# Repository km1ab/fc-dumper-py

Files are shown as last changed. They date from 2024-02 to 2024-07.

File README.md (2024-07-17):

# FC dumper py

- Dumper for fc by Python.
- This dumper is a HAT for Raspberry Pi and we also publish the source code to make it work in this repository.

## Environment
- Raspberry pi 3 b+, or later
- Raspberry pi zero, or later

```
Unsupported on Raspberry pi 5. "RPi.GPIO" is no longer available from Raspberry pi 5. 
We are currently looking into alternatives.
```

## How to use
At Raspberry pi, or remote connecting (ex ssh,...)
```
pip install RPi.GPIO
python3 fc_dumper.py -o filename
```

```
$ python3 fc_dumpter.py --help
usage: fc_dumpter.py [-h] [-o OUTPUT_FILE] [-p {8K,16K,32K}] [-c {1K,8K,16K,32K}] [-a {mapper0,mapper1,mapper3,mapper66,mapper23}] [-m {dumper,led_test}] [-d [DEBUG]] [-i [INFO]] [-s SIZE]
                     [-D [LED_DUTY ...]] [-F [LED_FREQ ...]] [-N [LED_NUMBER ...]] [-T LED_TIME]

options:
  -h, --help            show this help message and exit
  -o OUTPUT_FILE, --output_file OUTPUT_FILE
                        output file name; (default: output.nes)
  -p {8K,16K,32K}, --prg_rom_size {8K,16K,32K}
                        program rom size select; (default: 16K)
  -c {1K,8K,16K,32K}, --chr_rom_size {1K,8K,16K,32K}
                        charactor rom size select; (default: 8K)
  -a {mapper0,mapper1,mapper3,mapper66,mapper23}, --mapper {mapper0,mapper1,mapper3,mapper66,mapper23}
                        mapper select; In mapper 23, specify the size of the bank in options '-p' and '-c'. (default: mapper0)
  -m {dumper,led_test}, --mode {dumper,led_test}
                        mode (default: dumper)
  -d [DEBUG], --debug [DEBUG]
                        debug log (default: False)
  -i [INFO], --info [INFO]
                        game infomation (default: False)
  -s SIZE, --size SIZE  read size (default: 256)
  -D [LED_DUTY ...], --led_duty [LED_DUTY ...]
                        LED testing only (default: [1])
  -F [LED_FREQ ...], --led_freq [LED_FREQ ...]
                        LED testing only (default: [20])
  -N [LED_NUMBER ...], --led_number [LED_NUMBER ...]
                        LED testing only (default: [0])
  -T LED_TIME, --led_time LED_TIME
                        LED testing only (default: 5)
```

## Hardware
- PCB-top
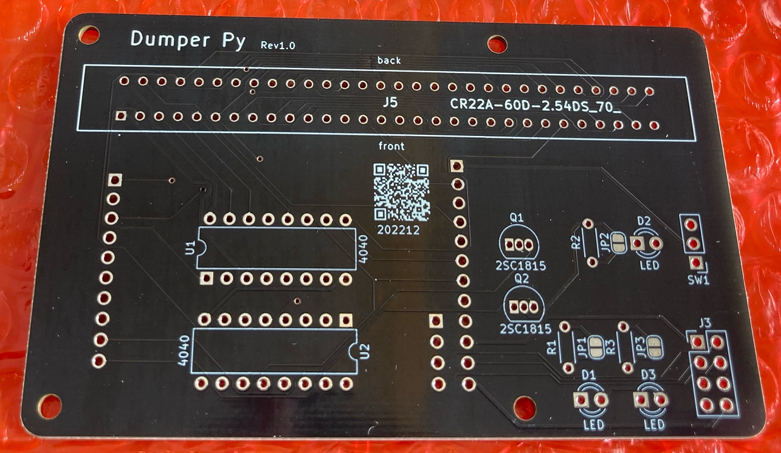
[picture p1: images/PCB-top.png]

- PCB-bottom
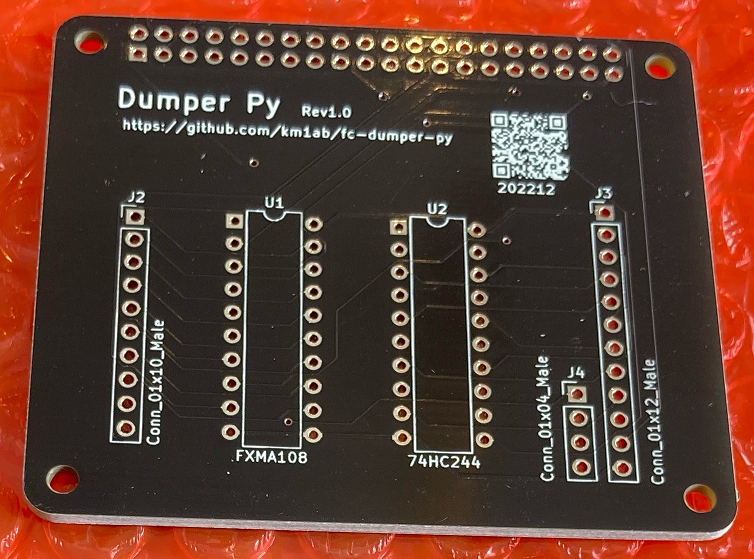
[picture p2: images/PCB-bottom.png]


## Parts list
必須

| 名称 | 数量 | 入手先 | 備考 |
|---|----|---|---|
| PCB-top (rev1.0) | 1  | 頒布予定 | 本ページのHardwareを参照 |
| PCB-bottom (rev1.0) | 1  | 頒布予定 | 本ページのHardwareを参照 |
| ラズパイ 3 b+ | 1  | メルカリ？など  | ラズパイ5が発売されました。少々高いですが、容量の少ない方が比較的入手しやすいようです。2024/03現在。 |
| CR22A-60D-2.54DS(70) | 1  | ⇒⇒⇒ | googleにて、CR22A-60D-2.54DS(70)で検索すると、ある程度ヒットします。 |
| 抵抗内蔵５ｍｍＬＥＤ（※） | 1  | 秋月電子 | https://akizukidenshi.com/catalog/g/gI-12517/ |
| 小型スライドスイッチ　１回路２接点 | 1  | 秋月電子 | https://akizukidenshi.com/catalog/g/gP-12723/ |
| 8ビット双方向ロジックレベル変換モジュール（FXMA108） | 1  | 秋月電子 | https://akizukidenshi.com/catalog/g/g104522/ |
| 74HC244 | 1  | マルツオンライン | https://www.marutsu.co.jp/GoodsDetail.jsp?salesGoodsCode=37576&shopNo=3 |
| 74HC4040 | 2  | マルツオンライン | https://www.marutsu.co.jp/pc/i/18963/ |
| Raspberry Pi専用スペーサー（MPS-M2611） | 1  | サンハヤト | https://shop.sunhayato.co.jp/products/mps-m2611 |
| 六角オネジ・メネジ　ＭＢ２６－１１ | 4  | 秋月電子 | https://akizukidenshi.com/catalog/g/gP-11546/ |
| ピンソケット (メス) 2×20 (40P) | 1  | 秋月電子 | https://akizukidenshi.com/catalog/g/g100085/ |
| ピンソケット(メス) 1×12(12P) | 1  | 秋月電子 | https://akizukidenshi.com/catalog/g/g110101/ |
| ピンソケット(メス) 1×10(10P) | 1  | 秋月電子 | https://akizukidenshi.com/catalog/g/g103786/ |
| ピンヘッダ 1×4 (4P)　10個入り（※） | 1  | 秋月電子 | https://akizukidenshi.com/catalog/g/g103950/ |
| ピンヘッダ 1×40 (40P) | 1  | 秋月電子 | https://akizukidenshi.com/catalog/g/g100167/ |
| ICソケット (16P)　10個入り（※） | 1  | 秋月電子 | https://akizukidenshi.com/catalog/g/g100007/ |
| ICソケット (20P)　10個入り（※） | 1  | 秋月電子 | https://akizukidenshi.com/catalog/g/g100009/ |

※LEDは、いかにも電源ONでスライドスイッチ真横のLED(D2)が光りそうですが、実際D3の方が光ります。<br>
　また、必ずしも内臓抵抗のものである必要がありません。<br>
　5mm LEDと抵抗の組み合わせでも良いです。<br>
　回路図をご覧頂くとわかるかと思います。<br>
※ピンヘッダ 1×4 (4P)は、1個しか使いません。バラで購入できるならそれで問題ありません。<br>
※ICソケットはそれぞれ2個使います。バラで購入できるならそれで問題ありません。<br>
　ただ、ICソケットは有りでも無しでも好きな方で。<br>

#### オプション
- 抵抗内蔵５ｍｍＬＥＤ x2
- トランジスタ　２ＳＣ１８１５ x2
- ※抵抗内蔵LEDを使わない場合は、抵抗x3（抵抗値はLEDのスペックによる）
- Bottom ケース：3Dプリンタで作りました。3B+用に適当に作っています　(データ：stl/raspi_case_4_2.stl)
- ピンヘッダ 2×20 (40P) ※2x4(8P)分しか使いません。デバッグ用なので無くても問題ありせん。
### 完成図
- ラズパイと接続するとこのような見た目になります。
- ２段のスタック構造になっています。
- ※Raspberry Pi専用スペーサーのナットは使いませんでした。

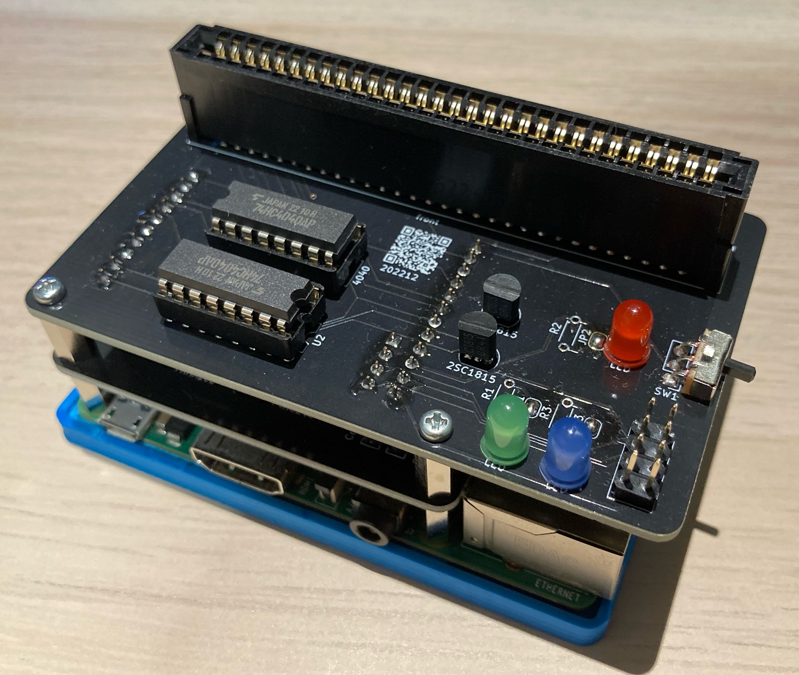
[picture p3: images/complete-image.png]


### 分割した様子
#### face and bottom
- face
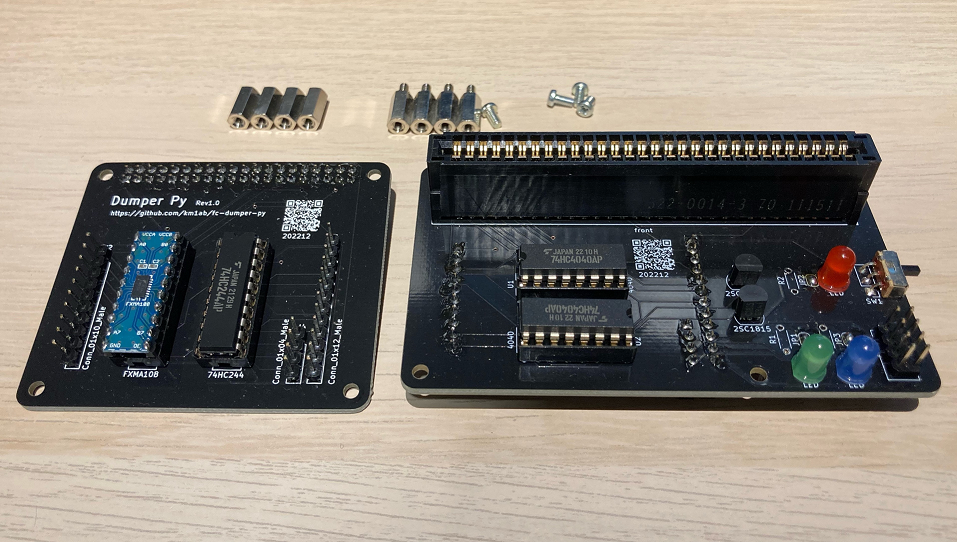
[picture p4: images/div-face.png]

- bottom
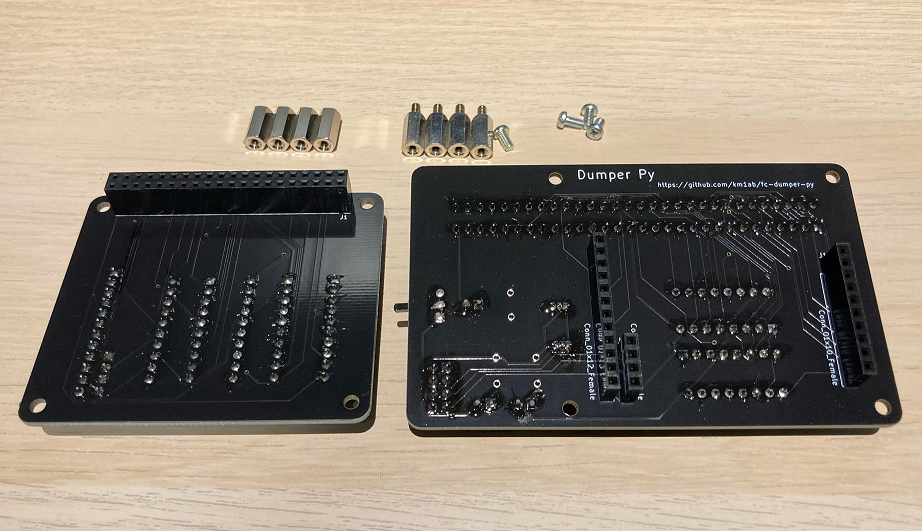
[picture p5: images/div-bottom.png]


### 留意事項
#### FXMA108の取り付けについて
- FXMA108のキットは、付属のピンヘッダをそのまま取り付けると、隣のHC244より背が高くなります。<br>それに伴い、PCB-TOPをスタックする時に干渉してしまいますので、以下に取付方法を記載致します。
- 方法１
  - ピンヘッダの足を適当な長さに切りそろえて下さい。
  - また、付属のピンヘッダの足は太いので、ICソケットに若干強引に差し込みます（問題なくささりますが）。
  - なので、気になる方は細ピンヘッダを使うと良いかもしれません。
- もう１つの方法
  - ICソケットも、ピンヘッダも使わずに直に取り付けてしまう方法です。
  - FXMA108のキットに以下のような説明がありました。簡単な方をお試しください。
```
スルーホール部分をルータ加工することで、ユニバーサル基板等に直接ハンダ付け可能となっています。（※）
```
※8ビット双方向ロジックレベル変換モジュールのマニュアルより引用。

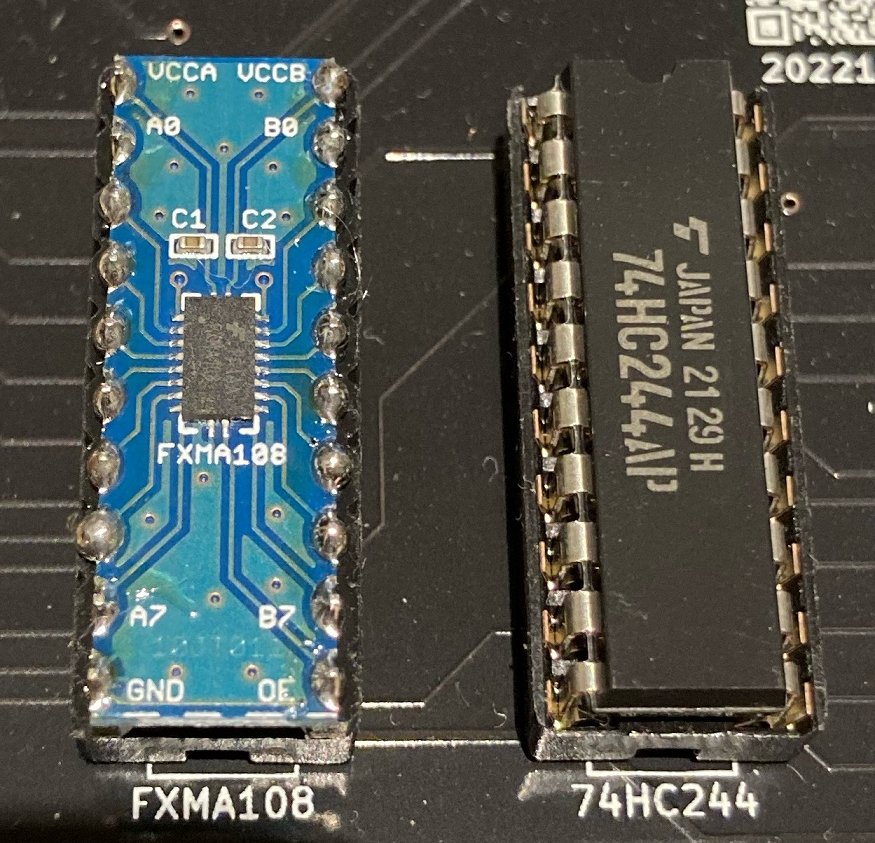
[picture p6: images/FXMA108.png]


### PCB design

#### top PCB
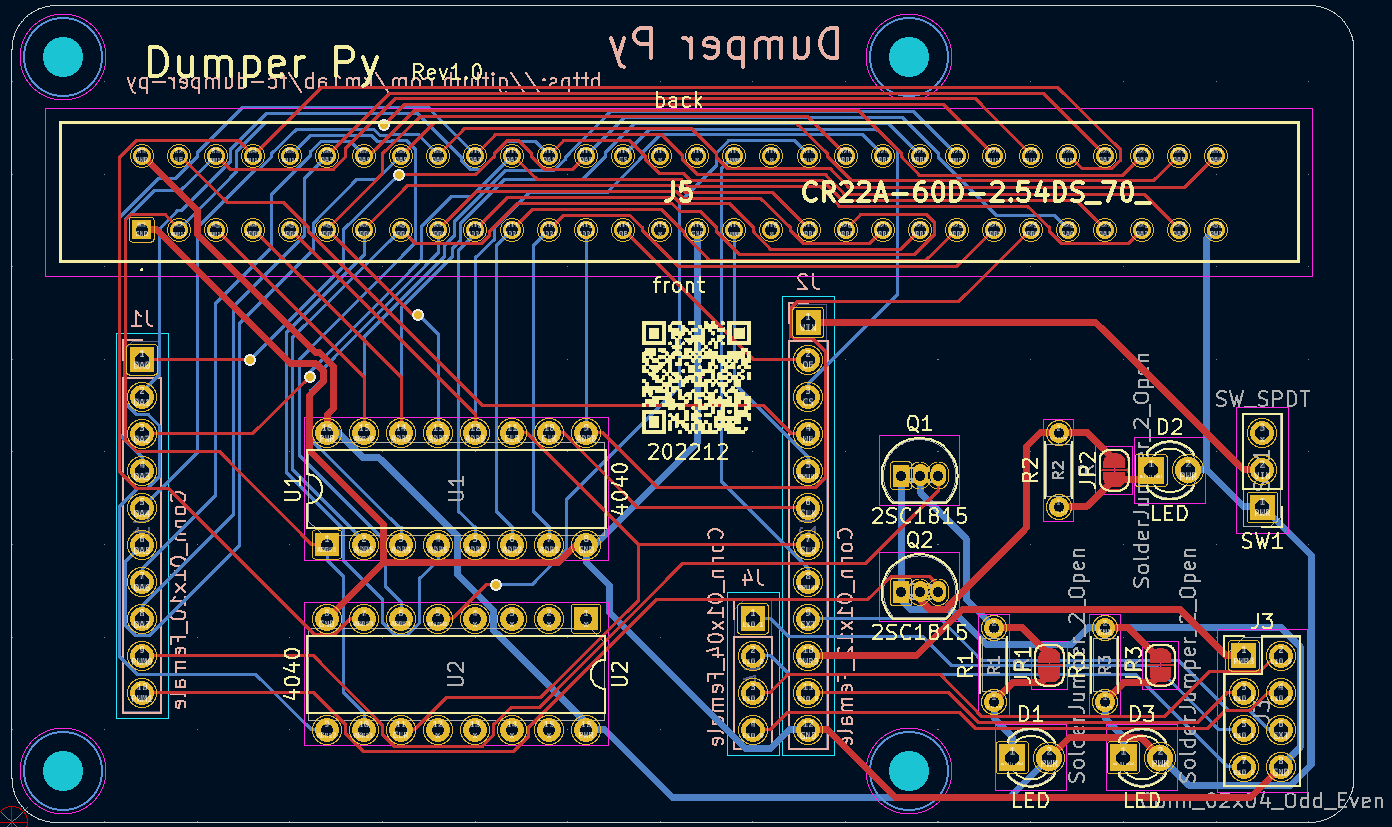
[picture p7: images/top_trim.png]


#### bottom PCB
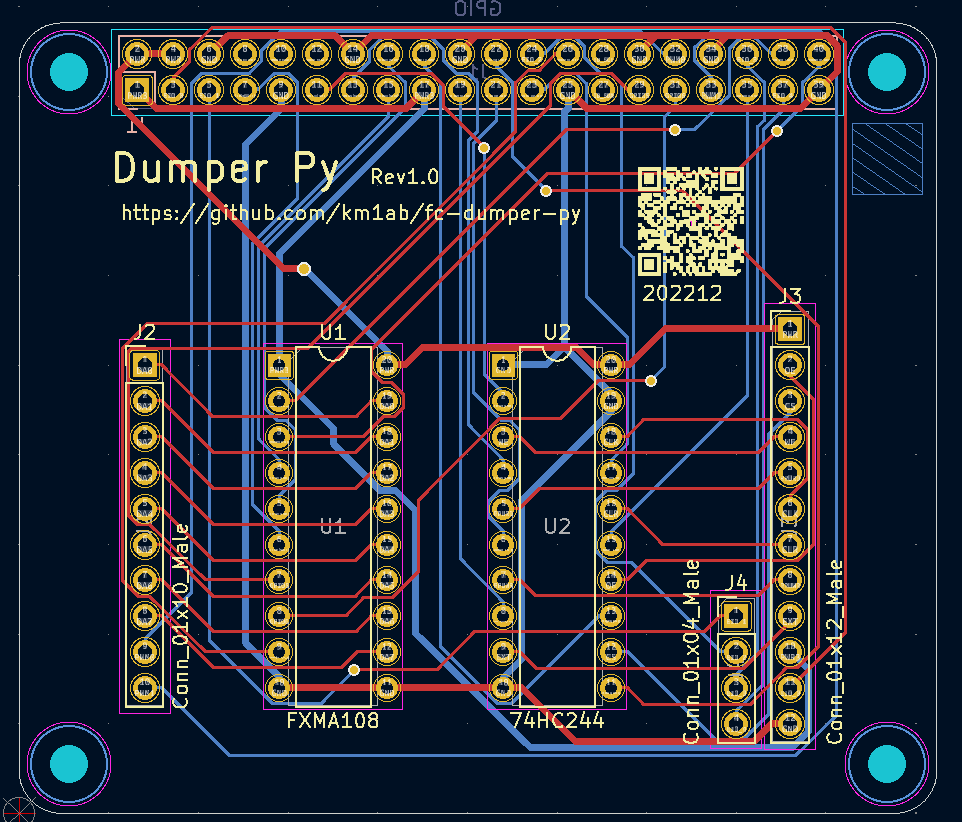
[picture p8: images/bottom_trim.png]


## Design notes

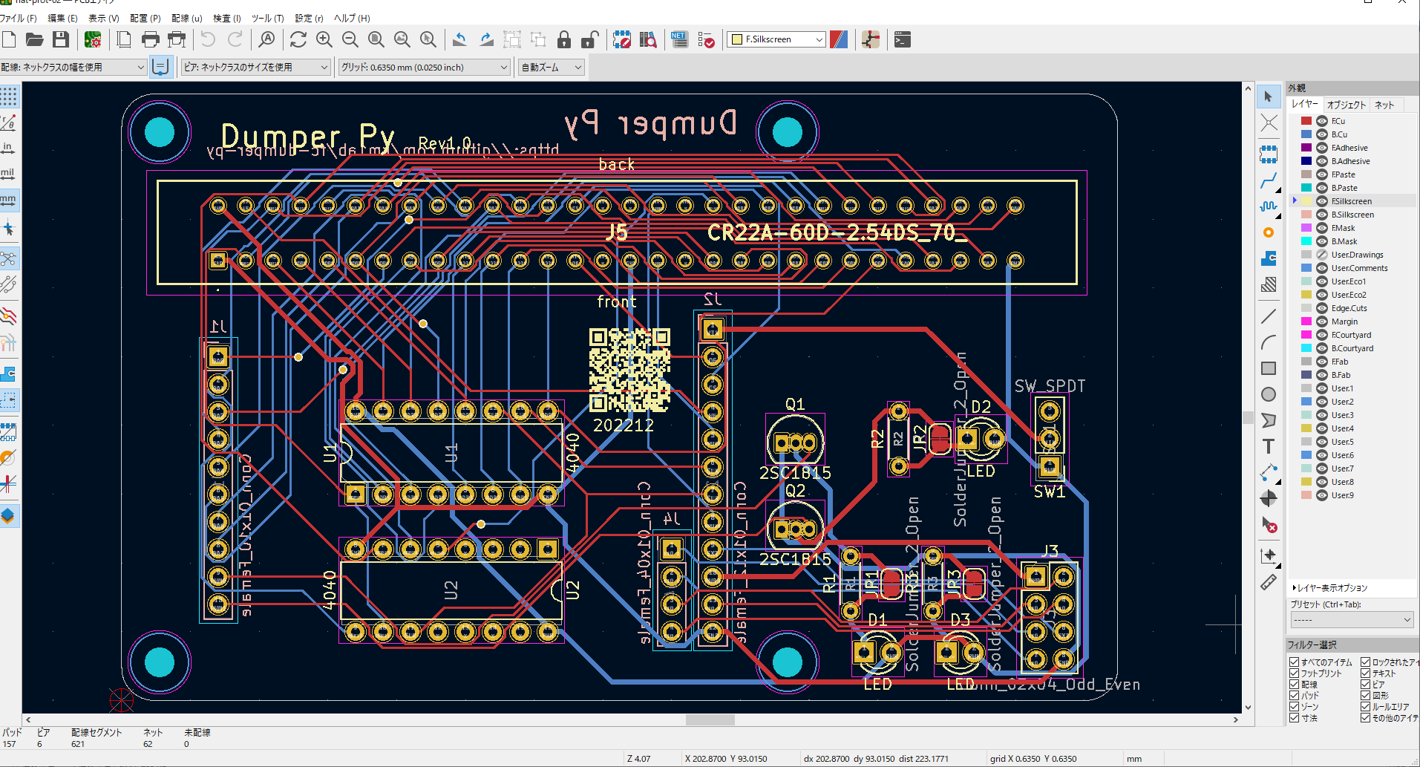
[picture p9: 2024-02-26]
images/top.PNG

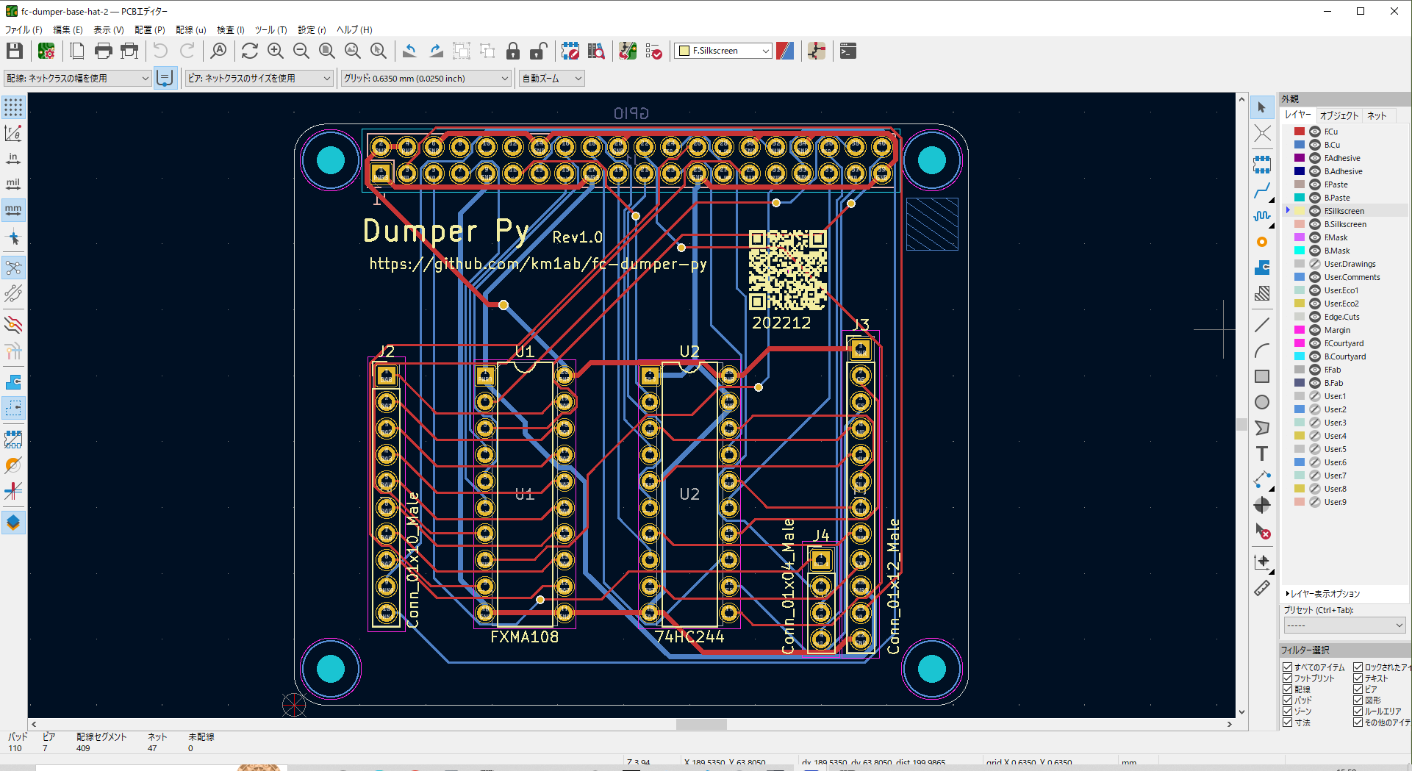
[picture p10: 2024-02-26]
images/bottom.PNG

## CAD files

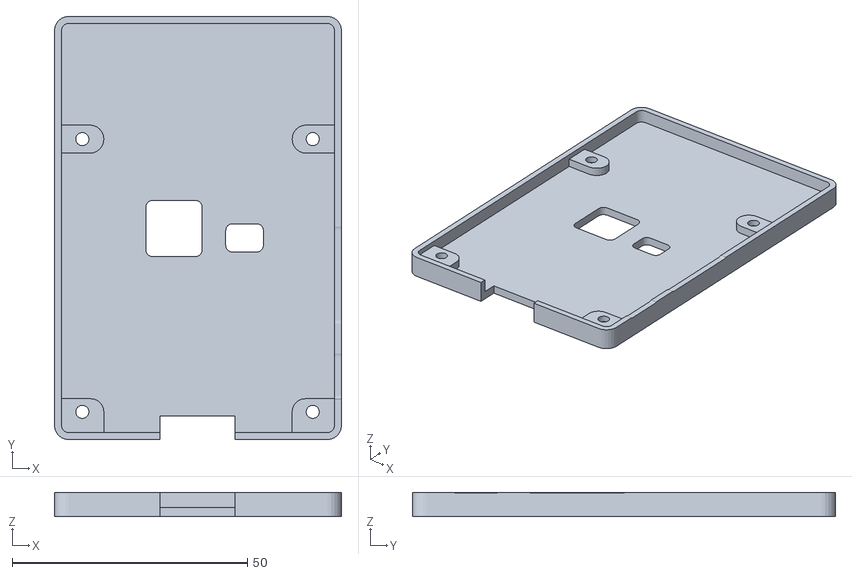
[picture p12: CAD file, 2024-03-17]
stl/raspi_case_4_2.stl
61.0 x 90.0 x 5.20

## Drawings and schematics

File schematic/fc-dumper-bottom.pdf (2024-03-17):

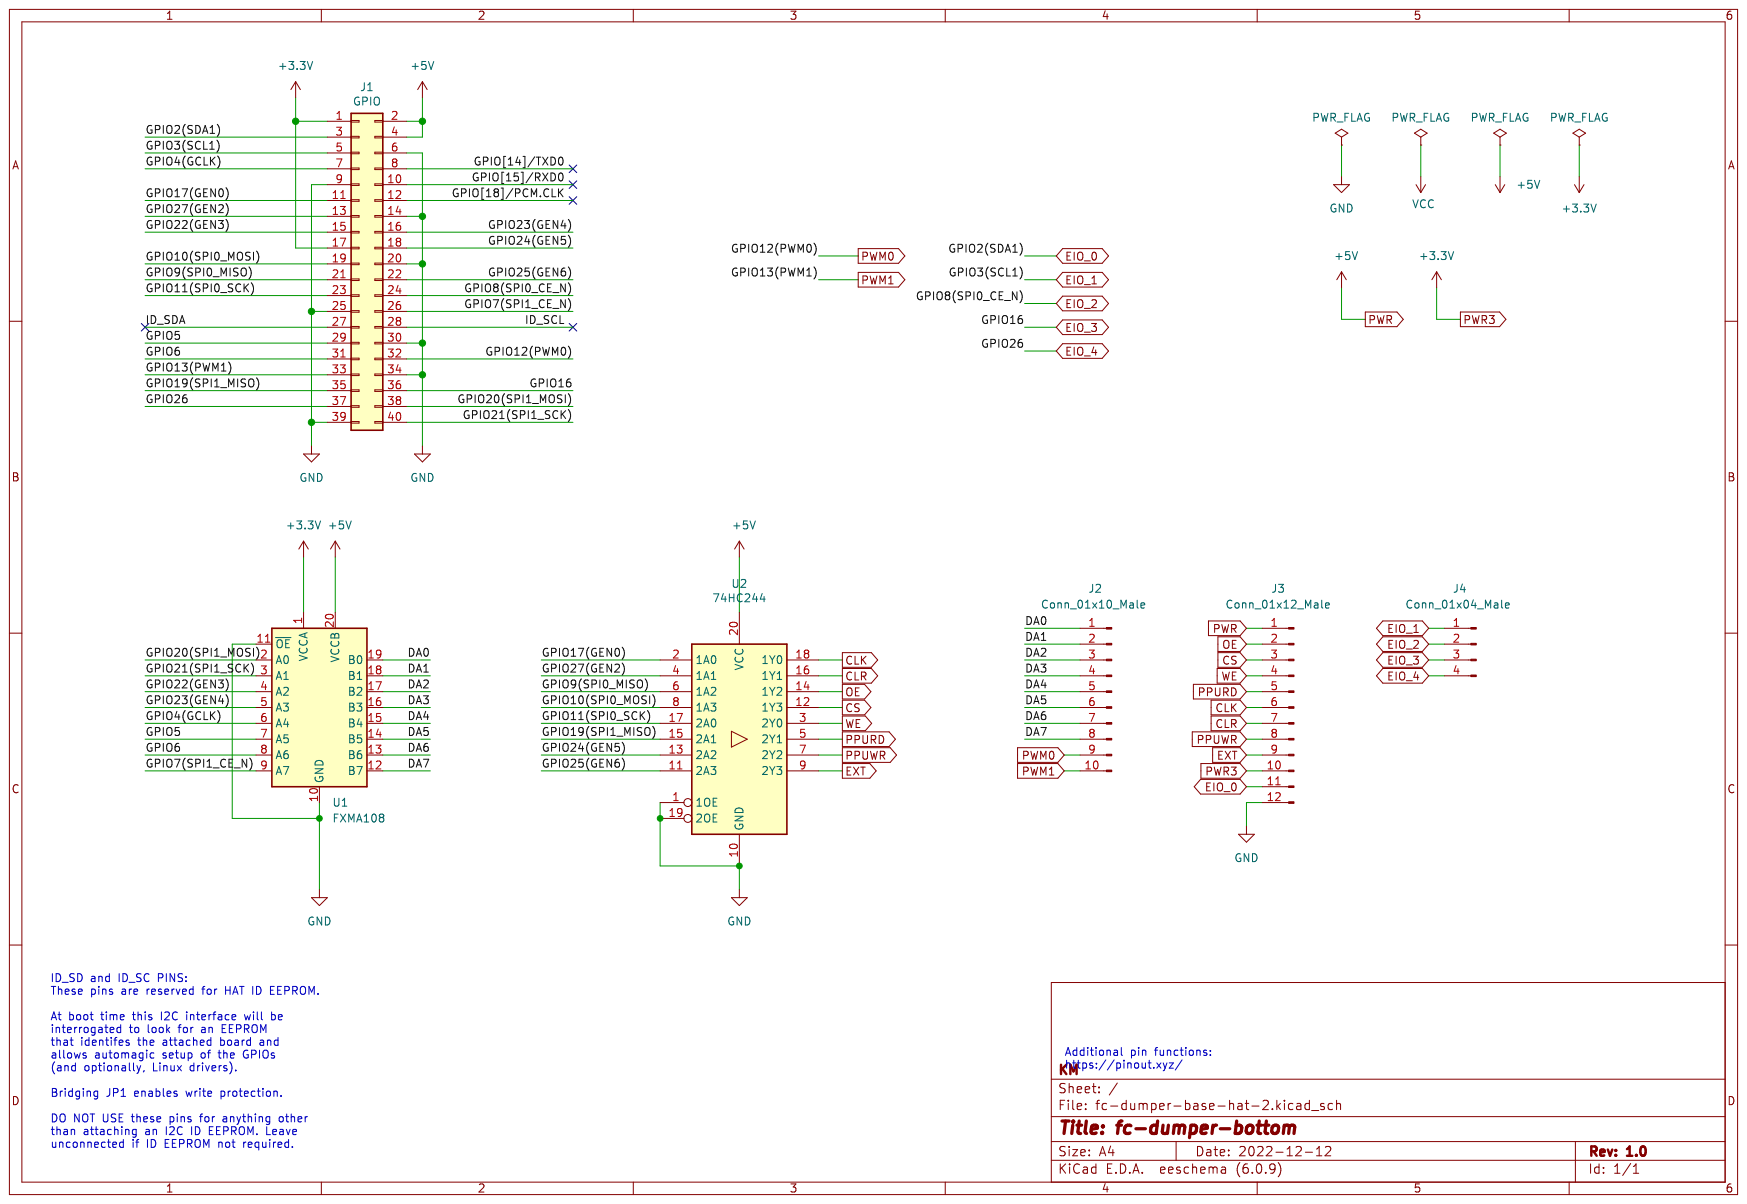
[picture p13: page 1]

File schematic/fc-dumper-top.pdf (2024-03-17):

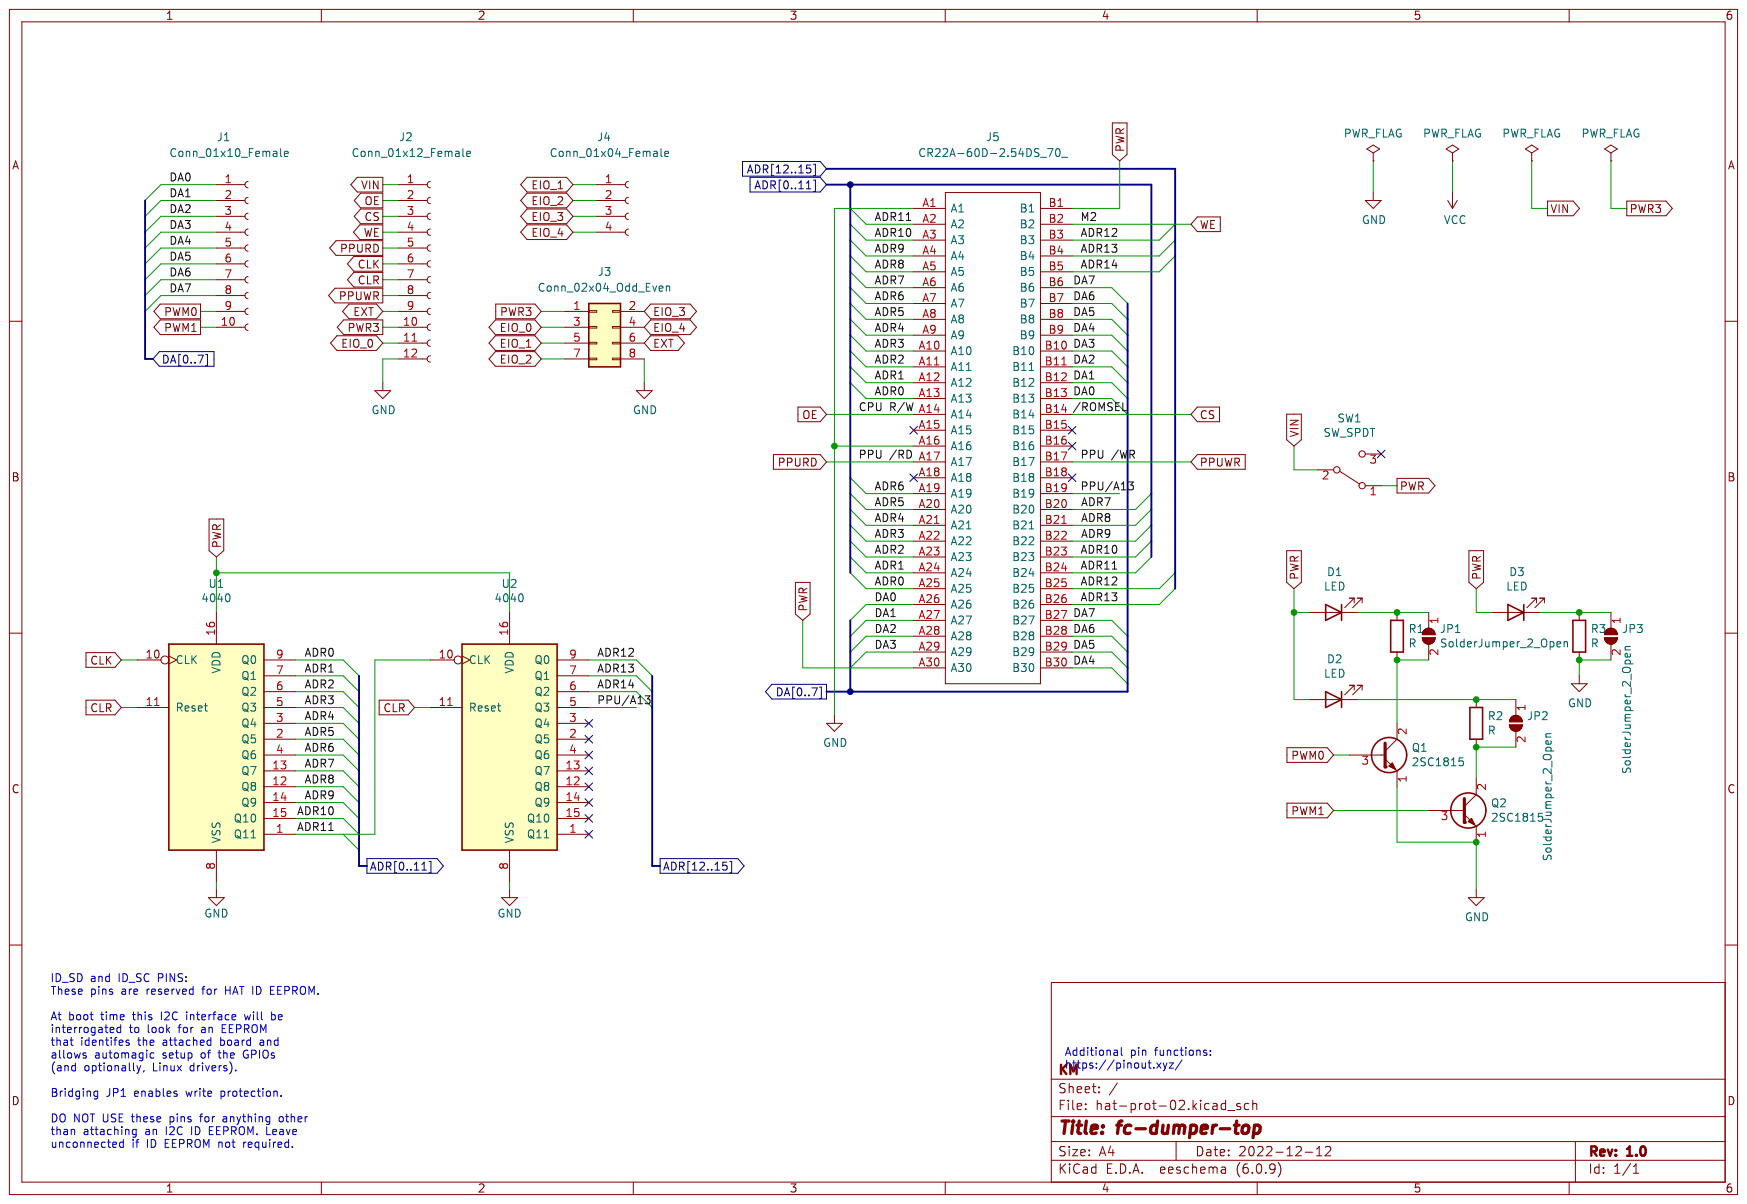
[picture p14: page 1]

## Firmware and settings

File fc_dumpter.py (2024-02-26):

import sys
import RPi.GPIO as GPIO
import time
from argparse import ArgumentParser, ArgumentDefaultsHelpFormatter

INTV = 0.005
# CLK	#RESET
port_tbl_addr_ctrl = [17, 27]

port_tbl_data_ctrl = [20, 21, 22, 23, 4, 5, 6, 7]
# CPU R/W	# /ROMSEL	# M2	# PPU /RD   # PPU /WR  # EXT PIN
port_tbl_port_ctrl = [9, 10, 11, 19, 24, 25]

# PWM0 # PWM1
port_tbl_pwm_ctrl = [12, 13]

HEADER_DATA_COMMON = [0x4E, 0x45, 0x53, 0x1A]

HEADER_DATA_COMMON_FOOTER = [0x00, 0x00, 0x00, 0x00, 0x00, 0x00, 0x00, 0x00]
HEADER_DATA_MAPPER0 = [
    # mapper 0
    0x01,
    0x01,
    0x00,
    0x00,
]

HEADER_DATA_MAPPER3 = [
    # mapper 3
    0x02,
    0x04,
    0x31,
    0x00,
]

HEADER_DATA_MAPPER66 = [
    # mapper 66
    0x08,
    0x04,
    0x21,
    0x40,
]

HEADER_DATA_MAPPER1 = [
    # mapper 1
    0x10,
    0x00,
    0x10,
    0x00,
]

HEADER_DATA_MAPPER23 = [
    # mapper 23
    0x08,
    0x10,
    0x71,
    0x10,
]

SIZE_1K = "1K"
SIZE_8K = "8K"
SIZE_16K = "16K"
SIZE_32K = "32K"
# SIZE_64K = "64K"
# SIZE_128K = "128K"
# rom_size: int = 0x4000  # PRG-ROM 16K
# chr_size: int = 0x2000  # CHR-ROM 8K
ROM_SIZE_DICT = {SIZE_1K: 0x400, SIZE_8K: 0x2000, SIZE_16K: 0x4000, SIZE_32K: 0x8000}

BANK_KEY_LIST = [0x30, 0x31, 0x32, 0x33]  # mapper3
BANK_KEY_MAPPER66_LIST0 = [0x00, 0x11, 0x22, 0x33]  # 4bank
# BANK_KEY_MAPPER66_LIST0 = [0x00, 0x10, 0x20, 0x30]  # 4bank
# BANK_KEY_MAPPER66_LIST1 = [0x30, 0x31, 0x32, 0x33]  # 4bank
# BANK_KEY_MAPPER66_LIST1 = [0x00, 0x01, 0x02, 0x03] # 4bank

BANK_KEY_MAPPER1_CTRL_REG = 0x1F  # chr bank 4KB, bank size 16KB, 4 screen, scroll H
BANK_HOME_MAPPER1 = 0xC000  # 0xC000 - 0xFFFF
BANK_AREA_MAPPER1 = 0x8000  # 0x8000 - 0xBFFF
BANK_PRG_REGISTER = 0xE000  # 0xE000 - 0xFFFF


def init_port(data_in: bool = True):
    GPIO.setmode(GPIO.BCM)
    for d in port_tbl_addr_ctrl:
        GPIO.setup(d, GPIO.OUT)
    if data_in:
        set_data_ctrl_to_intput()
    else:
        set_data_ctrl_to_output()
    for d in port_tbl_port_ctrl:
        GPIO.setup(d, GPIO.OUT)
    for d in port_tbl_pwm_ctrl:
        GPIO.setup(d, GPIO.OUT)
        GPIO.output(d, False)


def term_port():
    GPIO.cleanup()


def set_data_ctrl_to_intput():
    for d in port_tbl_data_ctrl:
        GPIO.setup(d, GPIO.IN, pull_up_down=GPIO.PUD_DOWN)


def set_data_ctrl_to_output():
    for d in port_tbl_data_ctrl:
        GPIO.setup(d, GPIO.OUT)


def gpio_out(d, f):
    GPIO.output(d, f)


def gpio_in(d):
    return GPIO.input(d)


def gpio_get_data():
    ret = (
        ((gpio_in(port_tbl_data_ctrl[0]) << 0))
        | ((gpio_in(port_tbl_data_ctrl[1]) << 1))
        | ((gpio_in(port_tbl_data_ctrl[2]) << 2))
        | ((gpio_in(port_tbl_data_ctrl[3]) << 3))
        | ((gpio_in(port_tbl_data_ctrl[4]) << 4))
        | ((gpio_in(port_tbl_data_ctrl[5]) << 5))
        | ((gpio_in(port_tbl_data_ctrl[6]) << 6))
        | ((gpio_in(port_tbl_data_ctrl[7]) << 7))
    )
    return ret


# 	print(ret)
# 	return ord(hex(ret))


def gpio_set_data(data: int):
    gpio_out(port_tbl_data_ctrl[0], (data >> 0) & 0x1)
    gpio_out(port_tbl_data_ctrl[1], (data >> 1) & 0x1)
    gpio_out(port_tbl_data_ctrl[2], (data >> 2) & 0x1)
    gpio_out(port_tbl_data_ctrl[3], (data >> 3) & 0x1)
    gpio_out(port_tbl_data_ctrl[4], (data >> 4) & 0x1)
    gpio_out(port_tbl_data_ctrl[5], (data >> 5) & 0x1)
    gpio_out(port_tbl_data_ctrl[6], (data >> 6) & 0x1)
    gpio_out(port_tbl_data_ctrl[7], (data >> 7) & 0x1)


def clear_addr():
    gpio_out(port_tbl_addr_ctrl[1], True)
    gpio_out(port_tbl_addr_ctrl[1], False)


def set_address(addr):
    gpio_out(port_tbl_addr_ctrl[0], True)
    gpio_out(port_tbl_addr_ctrl[1], True)
    time.sleep(INTV)
    gpio_out(port_tbl_addr_ctrl[1], False)
    for i in range(addr):
        gpio_out(port_tbl_addr_ctrl[0], False)
        gpio_out(port_tbl_addr_ctrl[0], True)


def inc_address():
    gpio_out(port_tbl_addr_ctrl[0], False)
    gpio_out(port_tbl_addr_ctrl[0], True)


def set_port_ctrl(i):
    gpio_out(port_tbl_port_ctrl[i], True)


def clear_port_ctrl(i):
    gpio_out(port_tbl_port_ctrl[i], False)


def set_cpu_rw():
    set_port_ctrl(0)


def unset_cpu_rw():
    clear_port_ctrl(0)


def set_romsel():
    set_port_ctrl(1)


def unset_romsel():
    clear_port_ctrl(1)


def set_m2_o2():
    set_port_ctrl(2)


def unset_m2_o2():
    clear_port_ctrl(2)


def set_ppu_w():
    set_port_ctrl(4)


def unset_ppu_w():
    clear_port_ctrl(4)


def set_ppu_r():
    set_port_ctrl(3)


def unset_ppu_r():
    clear_port_ctrl(3)


def set_data(data: int):
    gpio_set_data(data)


def read_rom(addr, chrsize) -> list:
    clear_addr()
    time.sleep(INTV)
    set_address(addr)
    time.sleep(INTV)
    output = []
    for i in range(chrsize):
        # print(chr(gpio_get_data()), end='')
        time.sleep(INTV)
        # gpio_get_data()
        output.append(gpio_get_data())
        inc_address()
    print("")
    return output


class Debug:
    def __init__(self) -> None:
        pass

    def dbg_log(self, log: str):
        print(log)

    def dbg_print(self, log_msg, kaigyo: bool = True):
        if kaigyo:
            print(log_msg)
        else:
            print(log_msg, end="")


class DebugDummy(Debug):
    def __init__(self) -> None:
        pass

    def dbg_log(self, log: str):
        pass
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

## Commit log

2024-02-26 add QR code to botom-PCB update design add version silk
2024-02-26 add tools, gerber data complete gerber
    [fc_dumper_base.GBL, fc_dumper_base.GBO, fc_dumper_base.GBS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]
2024-02-26 add option, led test, add select option (size and mapper)
2024-03-17 update doc and PCB images
2024-03-17 add 3d print data (stl)
    [raspi_case_4_2.stl]
2024-03-17 add schematic
